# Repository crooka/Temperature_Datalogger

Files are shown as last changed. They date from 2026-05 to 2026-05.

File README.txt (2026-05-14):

Reach out to andrew.crook@usu.edu with any questions. 

Use 1 Oz copper
Green soldermask preferred

Most parts have links to both Digikey and JLCPCB. JLCPCB is the preferred supplier, but the big capacitors will need to come from digikey. 
UPDATE: due to cost, I'm only getting the top side assembled, and I'm not getting the ESP32 put on because that will drive up cost. Planning to put the ESP32 with solder paste and the reflow oven at work, and hand solder the back side. 

This section is so I can keep track of what's for what. 
Component purpose/notes:

R11,R12: 	Tell usb to send over 5V
C11,C13,C14,C15:Clean up power to sensors and some ESD protection
C7,C3,C6,C5: 	Clean up power from AMS1117
AMS1117: 	Linear voltage regulator to convert 5V to 3.3V (This is isn't as efficient as a buck converter)
D1: 		Probably not necessary, but this is back current protection. It was in the example. 
R5,R8:		Pull up resistors for the buttons

ESP32: 		This is the brains. Pushing the enable button should reset the board, The IO0 button should make it enter boot mode. 

TMP117: Maybe add in a zero ohm resistor option later so gpio16 can be used for either temperature interrupts or broken out for general IO depending on the assembly? 
	Verify that tying ADD0 to GND gives I2C address 0x48.
	Using recommended 4.7Kohm pull up resistor for SDA and SCL. One source said 2.2K may be better?  

BH1750: Tie ADDR to GND for I2C address 0x23

BME280 Tie CSB to VDDIO for I2C (tie to GND for SPI) With I2C selected, tie SDO to GND for I2C address 0x76

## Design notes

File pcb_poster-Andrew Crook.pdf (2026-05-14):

# Temperature Datalogger

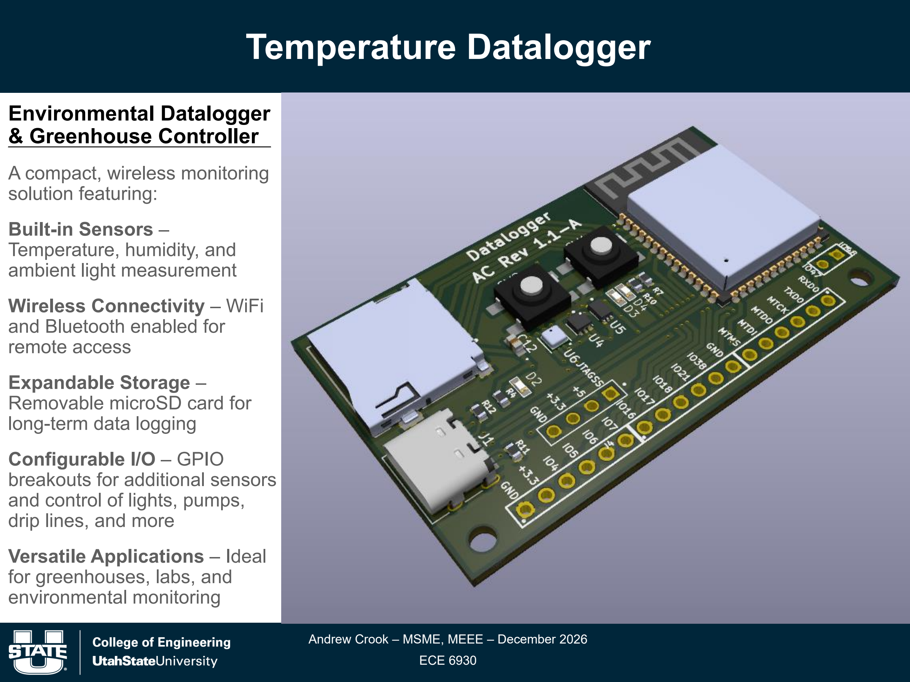
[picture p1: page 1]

Andrew Crook – MSME, MEEE – December 2026

ECE 6930

Environmental Datalogger
& Greenhouse Controller

A compact, wireless monitoring solution featuring:

Built-in Sensors –
Temperature, humidity, and ambient light measurement

Wireless Connectivity – WiFi and Bluetooth enabled for
remote access

Expandable Storage –
Removable microSD card for long-term data logging

Configurable I/O – GPIO
breakouts for additional sensors and control of lights, pumps, drip lines, and more

Versatile Applications – Ideal for greenhouses, labs, and environmental monitoring

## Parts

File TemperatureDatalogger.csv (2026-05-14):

Source: | C:\Users\gecko\Desktop\classes\pcb\TemperatureDatalogger\TemperatureDatalogger.kicad_sch
Date: | 2025-11-14T09:51:00-0700
Tool: | Eeschema 9.0.4
Generator: | C:\Program Files\KiCad\9.0\bin\scripting\plugins/bom_csv_grouped_by_value.py
Component Count: | 40
Collated Components:
Item | Qty | Reference(s) | Value | LibPart | Footprint | Datasheet | DNP | AVAILABILITY | Availability | Check_prices | DESCRIPTION | DPN | DPR | Datasheet | Description | Description_1 | Digikey Link (backup part) | Digikey link | Footprint | JLCPCB | JLCPCB link | MANUFACTURER | MAXIMUM_PACKAGE_HEIGHT | MF | MFR | MP | MPN | MRF | PACKAGE | PARTREV | PRICE | PURCHASE-URL | Package | Price | SPN | SPR | STANDARD | Sim.Pins | SnapEDA_Link | Untitled Field
1 | 2 | C1, C7 | 10uf RFS | WCAP-PSLP_4X5.5:WCAP-PSLP_4X5.5 | RF-A_NCH:RF-A_NCH-M | kicad-embed://e-rfs_rfa.pdf | DNP |  |  |  |  |  |  | kicad-embed://e-rfs_rfa.pdf |  |  |  | https://www.digikey.com/en/products/detail/nichicon/RFS1A100MCN1GB/2202796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 | RF-A_NCH:RF-A_NCH-M | https://jlcpcb.com/partdetail/Nichicon-RFS1A100MCN1GB/C2162094 |  |  |  |  | Nichicon |  | RFS1A100MCN1GB |  |  |  |  |  |  |  | 493-3682-1-ND | Digikey
2 | 9 | C2, C3, C4, C6, C11, C12, C13, C14, C15 | 100 nf | :CC0603KRX5R8BB104_1 | CC0603KRX5R8BB104:CAP_CC0603KRX5R8BB104_YAG-M | CC0603KRX5R8BB104 |  |  |  |  |  |  |  | CC0603KRX5R8BB104 |  |  |  | https://www.digikey.com/en/products/detail/yageo/CC0603KRX5R8BB104/20376210 | CC0603KRX5R8BB104:CAP_CC0603KRX5R8BB104_YAG-M |  | https://jlcpcb.com/partdetail/YAGEO-CC0603KRX5R8BB104/C2930551 |  |  |  | YAGEO |  | CC0603KRX5R8BB104 |  |  |  |  |  |  |  | C2930551 | JLCPCB
3 | 1 | C5 | 22uf WCAP | WCAP-PSLP_4X5.5:WCAP-PSLP_4X5.5 | WCAP-PSLP:WCAP-PSLP_4X5.5_DXL_ | kicad-embed://875105240003.pdf | DNP |  |  |  |  |  |  | kicad-embed://875105240003.pdf |  |  |  | https://www.digikey.com/en/products/detail/w%C3%BCrth-elektronik/875105240003/5147567 | WCAP-PSLP:WCAP-PSLP_4X5.5_DXL_ |  | https://jlcpcb.com/partdetail/WurthElektronik-875105240003/C2161805 |  |  |  | Wurth Elektronik |  | 875105240003 |  |  |  |  |  |  |  | 732-6403-1-ND - Cut Tape (CT) | Digikey
4 | 1 | D1 | D_Schottky | Device:D_Schottky | Schottkey:DO-214AC_VIS-M | kicad-embed://bys10.pdf |  |  |  |  |  |  |  | kicad-embed://bys10.pdf | Schottky diode |  |  | https://www.digikey.com/en/products/detail/vishay-general-semiconductor-diodes-division/BYS10-25-E3-TR/2149781 | Schottkey:DO-214AC_VIS-M |  | https://jlcpcb.com/partdetail/VishayIntertech-BYS10_25_E3TR/C3008962 |  |  |  | Vishay Intertech |  | BYS10-25-E3/TR |  |  |  |  |  |  |  | C3008962 | JLCPCB
5 | 2 | D2, D4 | Green LED | Device:LED | LED:LED_0604_SMD | kicad-embed://150060VS55040.pdf |  |  |  |  |  |  |  | kicad-embed://150060VS55040.pdf | Light emitting diode |  |  | https://www.digikey.com/en/products/detail/w%C3%BCrth-elektronik/150060VS55040/8557182 | LED:LED_0604_SMD |  | https://jlcpcb.com/partdetail/WurthElektronik-150060VS55040/C6390388 |  |  |  |  |  | 150060VS55040 | Würth Elektronik |  |  |  |  |  |  | C6390388 | JLCPCB |  | 1=K 2=A
6 | 1 | D3 | Red LED | Device:LED | LED:LED_0604_SMD | kicad-embed://150060VS55040.pdf |  |  |  |  |  |  |  | kicad-embed://150060VS55040.pdf | Light emitting diode |  |  | https://www.digikey.com/en/products/detail/w%C3%BCrth-elektronik/150060RS75000/4489901 | LED:LED_0604_SMD |  | https://jlcpcb.com/partdetail/WurthElektronik-150060RS75000/C3030991 |  |  |  |  |  | 150060RS75000 | Würth Elektronik |  |  |  |  |  |  | C3030991 | JLCPCB |  | 1=K 2=A
7 | 1 | J1 | USB_C_Receptacle_USB2.0_16P | Connector:USB_C_Receptacle_USB2.0_16P | Connector_USB:USB_C_Receptacle_HRO_TYPE-C-31-M-12 | kicad-embed://C165948.pdf |  |  |  |  |  |  |  | kicad-embed://C165948.pdf | USB 2.0-only 16P Type-C Receptacle connector |  |  |  | Connector_USB:USB_C_Receptacle_HRO_TYPE-C-31-M-12 |  | https://jlcpcb.com/partdetail/Korean_HropartsElec-TYPE_C_31_M12/C165948 |  |  |  | Korean Hroparts Elec |  | TYPE-C-31-M-12 |  |  |  |  |  |  |  | C165948 | JLCPCB
8 | 1 | J2 | Micro_SD_Card | TF-01A:TF-01A | TF_01A:TF-01A | https://www.we-online.com/components/products/datasheet/693072010801.pdf |  |  | Not in stock | https://www.snapeda.com/parts/TF-01A/HRO+Electronics+Co.%252C+Ltd./view-part/?ref=eda |  |  |  | https://www.we-online.com/components/products/datasheet/693072010801.pdf | Micro SD Card Socket | Standard Card Edge Connectors |  |  | TF_01A:TF-01A |  | https://jlcpcb.com/parts/componentSearch?searchTxt=tf-01a |  |  | HRO Electronics Co., Ltd. | Korean Hroparts Elec | TF-01A | TF-01A |  |  |  |  |  | Package | None | C91145 | JLCPCB |  |  | https://www.snapeda.com/parts/TF-01A/HRO+Electronics+Co.%252C+Ltd./view-part/?ref=snap
9 | 3 | J3, J4, J15 | 6130XX11121_61300611121 | 6130XX11121_61300611121:6130XX11121_61300611121 | header6pin:61300611121 |  | DNP |  |  |  |  |  |  |  |  |  |  |  | header6pin:61300611121
10 | 1 | J5 | 61300411121 | 61300411121:61300411121 | header2_4pin:WURTH_61300411121 |  | DNP | In Stock |  |  | Connector Header Through Hole 4 position 0.100 (2.54mm) |  |  |  | Connector Header Through Hole 4 position 0.100 (2.54mm) |  |  |  | header2_4pin:WURTH_61300411121 |  |  |  |  | Würth Elektronik |  | 61300411121 |  |  | None |  | None | https://pricing.snapeda.com/search/part/61300411121/?ref=eda
11 | 1 | J6 | TSW-102-07-F-S | TSW-102-07-F-S:TSW-102-07-F-S | header2_4pin:SAMTEC_TSW-102-07-F-S |  | DNP |  |  |  |  |  |  |  |  |  |  |  | header2_4pin:SAMTEC_TSW-102-07-F-S |  |  | Samtec |  |  |  |  |  |  |  | R |  |  |  |  |  |  | Manufacturer Recommendations
12 | 2 | R1, R2 | 4.7K | RCS06035K10FKEA:RCS06035K10FKEA | 0_27k:RES_ERJPA3F2700V | kicad-embed://C4017867.pdf |  |  |  |  |  |  |  | kicad-embed://C4017867.pdf |  |  |  | https://www.digikey.com/en/products/detail/yageo/RC0603FR-074K7L/727212 | 0_27k:RES_ERJPA3F2700V |  | https://jlcpcb.com/partdetail/YAGEO-RC0603FR074K7L/C99782 |  |  |  | YAGEO |  | RC0603FR-074K7L |  |  |  |  |  |  |  | C99782 | JLCPCB
13 | 3 | R4, R7, R10 | 0.27k | RCS06035K10FKEA:RCS06035K10FKEA | 0_27k:RES_ERJPA3F2700V | kicad-embed://C4017867.pdf |  |  |  |  |  |  |  | kicad-embed://C4017867.pdf |  |  |  | https://www.digikey.com/en/products/detail/yageo/RC0603FR-13270RL/14286751 | 0_27k:RES_ERJPA3F2700V |  | https://jlcpcb.com/partdetail/YAGEO-RC0603FR13270RL/C4017867 |  |  |  | YAGEO |  | RC0603FR-13270RL |  |  |  |  |  |  |  | C4017867 | JLCPCB
14 | 2 | R5, R8 | 10k | RCS06035K10FKEA:RCS06035K10FKEA | 0_27k:RES_ERJPA3F2700V | kicad-embed://C4017867.pdf |  |  |  |  |  |  |  | kicad-embed://C4017867.pdf |  |  |  | https://www.digikey.com/en/products/detail/yageo/RC0603FR-0710KL/726880 | 0_27k:RES_ERJPA3F2700V |  | https://jlcpcb.com/partdetail/YAGEO-RC0603FR0710KL/C98220 |  |  |  | YAGEO |  | RC0603FR-0710KL |  |  |  |  |  |  |  | C98220 | JLCPCB
15 | 2 | R11, R12 | 5.1K | RCS06035K10FKEA:RCS06035K10FKEA | 0_27k:RES_ERJPA3F2700V | kicad-embed://C4017867.pdf |  |  |  |  |  |  |  | kicad-embed://C4017867.pdf |  |  |  | https://www.digikey.com/en/products/detail/yageo/RC0603FR-075K1L/727268 | 0_27k:RES_ERJPA3F2700V |  | https://jlcpcb.com/partdetail/YAGEO-RC0603FR075K1L/C105580 |  |  |  | YAGEO |  | RC0603FR-075K1L |  |  |  |  |  |  |  | C105580 | JLCPCB
16 | 2 | SW1, SW2 | SW_MEC_5E | Switch:SW_MEC_5E | TactileButton:button | kicad-embed://C306883.pdf |  |  |  |  |  |  |  | kicad-embed://C306883.pdf | MEC 5E single pole normally-open tactile switch |  |  | https://www.digikey.com/en/products/detail/omron-electronics-inc-emc-div/B3SN-3012P/9717 | TactileButton:button |  | https://jlcpcb.com/partdetail/OmronElectronics-B3SN3012P/C306881 |  |  |  | Omron Electronics |  | B3SN-3012P |  |  |  |  |  |  |  | C306881 | JLCPCB
17 | 1 | U1 | ESP32-S3-WROOM-1-N4 | ESP32-S3-WROOM-1-N4:ESP32-S3-WROOM-1-N4 | esp32:XCVR_ESP32-S3-WROOM-1-N4 | kicad-embed://esp32-s3-wroom-1_wroom-1u_datasheet_en.pdf |  |  |  |  |  |  |  | kicad-embed://esp32-s3-wroom-1_wroom-1u_datasheet_en.pdf |  |  |  | https://www.digikey.com/en/products/detail/espressif-systems/ESP32-S3-WROOM-1-N4/16162639 | esp32:XCVR_ESP32-S3-WROOM-1-N4 |  | https://jlcpcb.com/partdetail/3198295-ESP32_S3_WROOM_1N4/C2913197 | Espressif | 3.25mm |  | Espressif Systems |  | ESP32-S3-WROOM-1-N4 |  |  | v1.0 |  |  |  |  | C2913197 | JLCPCB | Manufacturer Recommendations
18 | 1 | U2 | USBLC6-2SC6 | USBLC6-2SC6:USBLC6-2SC6 | USBLC6:SOT95P280X145-6N | kicad-embed://en.CD00050750.pdf |  | In Stock | In Stock | https://www.snapeda.com/parts/USBLC6-2SC6/STMicroelectronics/view-part/?ref=eda | 17V Clamp 5A (8/20µs) Ipp Tvs Diode Surface Mount SOT-23-6 | C7519 | JLCPCB | kicad-embed://en.CD00050750.pdf | ESD protection for USB C | 17V Clamp 5A (8/20µs) Ipp Tvs Diode Surface Mount SOT-23-6 |  | https://www.digikey.com/en/products/detail/stmicroelectronics/USBLC6-2SC6/1040559 | USBLC6:SOT95P280X145-6N |  | https://jlcpcb.com/partdetail/STMicroelectronics-USBLC62SC6/C7519 |  |  | STMicroelectronics | STMicroelectronics | USBLC6-2SC6 | USBLC6-2SC6 |  | SOT-23-6 STMicroelectronics |  | None | https://pricing.snapeda.com/search/part/USBLC6-2SC6/?ref=eda | SOT-23-6 STMicroelectronics | None |  |  |  |  | https://www.snapeda.com/parts/USBLC6-2SC6/STMicroelectronics/view-part/?ref=snap
19 | 1 | U3 | AMS1117-3.3 | AMS1117-3.3:AMS1117-3.3 | AMS1117:SOT229P700X180-4N | kicad-embed://C6186.pdf |  | Unavailable | In Stock | https://www.snapeda.com/parts/AMS1117-3.3/UMW/view-part/?ref=eda |  |  |  | kicad-embed://C6186.pdf |  | Linear Voltage Regulator IC Positive Fixed 1 Output 1A SOT-223-3L | https://www.digikey.com/en/products/detail/evvo/AMS1117-3-3/22482148 |  | AMS1117:SOT229P700X180-4N |  | https://jlcpcb.com/partdetail/Advanced_MonolithicSystems-AMS1117_33/C6186 | Advanced Mololithic Systems |  | UMW | Advanced Monolithic Systems | AMS1117-3.3 | AMS1117-3.3 |  | SOT-223 ams | NA | None |  | SOT-223-3L UMW | None | C6186 | JLCPCB | IPC-7351B |  | https://www.snapeda.com/parts/AMS1117-3.3/UMW/view-part/?ref=snap
20 | 1 | U4 | TMP117MAIDRVR | TMP117MAIDRVR:TMP117MAIDRVR | TMP117:SON65P200X200X80-7N | kicad-embed://tmp117.pdf |  |  |  |  |  |  |  | kicad-embed://tmp117.pdf |  |  |  | https://www.digikey.com/en/products/detail/texas-instruments/TMP117MAIDRVR/9685285 | TMP117:SON65P200X200X80-7N |  | https://jlcpcb.com/partdetail/TexasInstruments-TMP117MAIDRVR/C2803242 |  |  |  | Texas Instruments |  | TMP117MAIDRVR |  |  |  |  |  |  |  | C2803242 | JLCPCB
21 | 1 | U5 | BH1750FVI-TR | BH1750FVI-TR:BH1750FVI-TR | BH1750:XDCR_BH1750FVI-TR | kicad-embed://bh1750fvi-e.pdf |  |  |  |  |  |  |  | kicad-embed://bh1750fvi-e.pdf |  |  |  | https://www.digikey.com/en/products/detail/rohm-semiconductor/BH1750FVI-TR/2041441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 | BH1750:XDCR_BH1750FVI-TR |  | https://jlcpcb.com/partdetail/ROHMSemicon-BH1750FVITR/C78960 | Rohm | 0.75mm |  | ROHM Semicon |  | BH1750FVI-TR |  |  | D |  |  |  |  | C78960 | JLCPCB | Manufacturer recommendations
22 | 1 | U6 | BME280 | BME280:BME280 | BME280:PSON65P250X250X100-8N | kicad-embed://bst-bme280-ds002.pdf |  | Good |  |  | Integrated pressure, humidity and temperature sensor; 8-pin 2.5x2.5x0.93mm LGA |  |  | kicad-embed://bst-bme280-ds002.pdf | Integrated pressure, humidity and temperature sensor; 8-pin 2.5x2.5x0.93mm LGA |  |  | https://www.digikey.com/en/products/detail/bosch-sensortec/BME280/6136306 | BME280:PSON65P250X250X100-8N |  | https://jlcpcb.com/parts/componentSearch?searchTxt=BME280 |  |  | Bosch | Bosch Sensortec | BME280 | BME280 |  | LGA-8 Bosch |  | 4.94 USD |  |  |  | C92489 | JLCPCB | IPC-7351B

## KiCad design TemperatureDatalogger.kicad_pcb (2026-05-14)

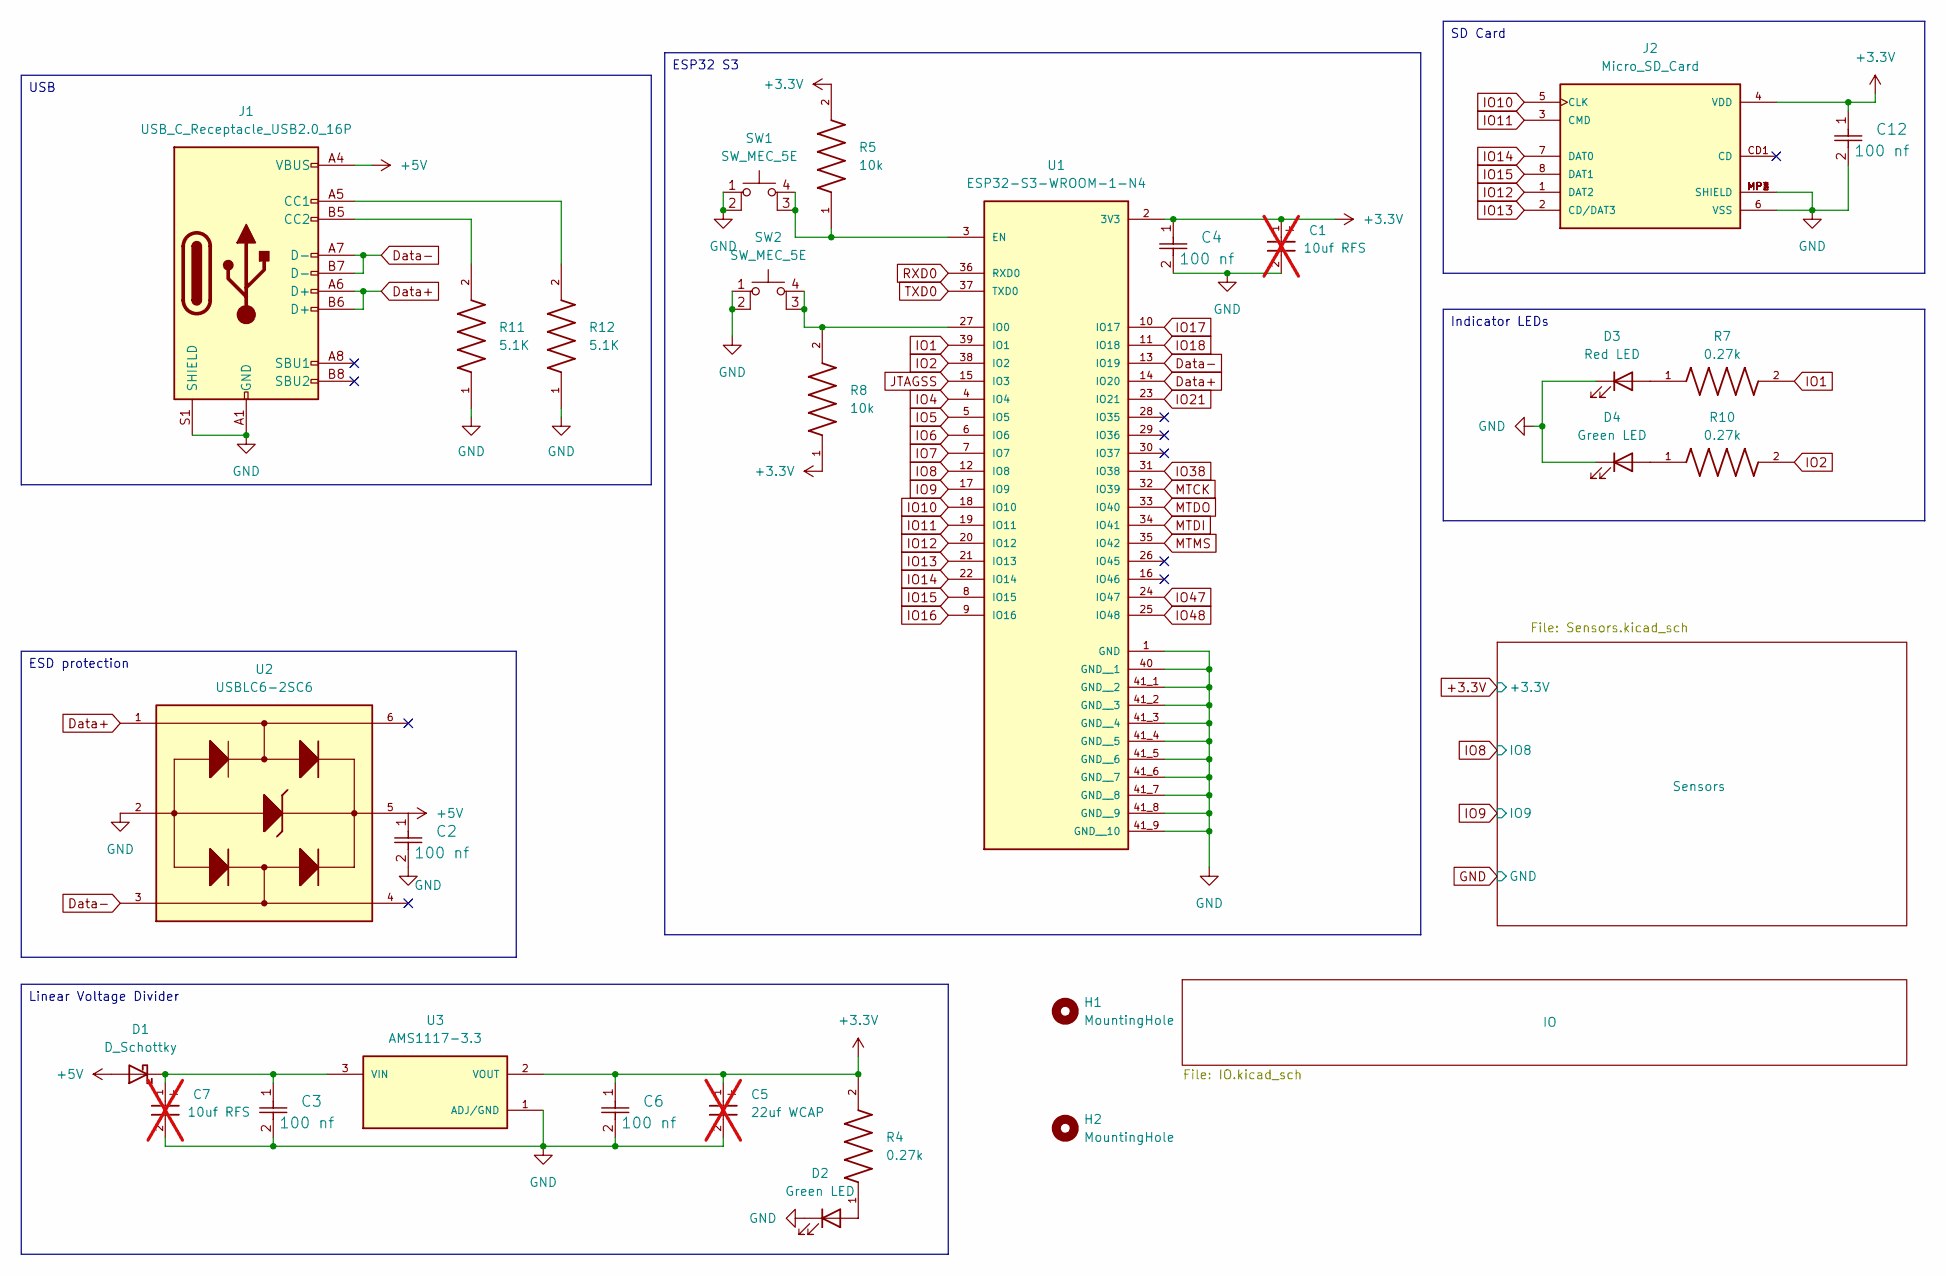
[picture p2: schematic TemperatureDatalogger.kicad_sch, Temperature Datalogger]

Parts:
C1, C7: 10uf RFS; RF-A_NCH-M; MPN RFS1A100MCN1GB; not fitted
C2, C3, C4, C6, C12: 100 nf; CAP_CC0603KRX5R8BB104_YAG-M; MPN CC0603KRX5R8BB104
C5: 22uf WCAP; WCAP-PSLP_4X5.5_DXL_; MPN 875105240003; not fitted
D1: D_Schottky; DO-214AC_VIS-M; MPN BYS10-25-E3/TR
D2, D4: Green LED; LED_0604_SMD; MPN 150060VS55040
D3: Red LED; LED_0604_SMD; MPN 150060RS75000
H1, H2: MountingHole; MountingHole_2.7mm_M2.5_ISO14580
J1: USB_C_Receptacle_USB2.0_16P; USB_C_Receptacle_HRO_TYPE-C-31-M-12; MPN TYPE-C-31-M-12
J2: Micro_SD_Card; TF-01A; MPN TF-01A
R4, R7, R10: 0.27k; RES_ERJPA3F2700V; MPN RC0603FR-13270RL
R5, R8: 10k; RES_ERJPA3F2700V; MPN RC0603FR-0710KL
R11, R12: 5.1K; RES_ERJPA3F2700V; MPN RC0603FR-075K1L
SW1, SW2: SW_MEC_5E; button; MPN B3SN-3012P
U1: ESP32-S3-WROOM-1-N4; XCVR_ESP32-S3-WROOM-1-N4; PARTREV v1.0
U2: USBLC6-2SC6; SOT95P280X145-6N; MPN USBLC6-2SC6
U3: AMS1117-3.3; SOT229P700X180-4N; PARTREV NA

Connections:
+3.3V: C1.1, C4.1, C5.1, C6.1, C12.1, J2.4 (VDD), R4.2, R5.2, R8.1, U1.2 (3V3), U3.2 (VOUT); also elsewhere on the board
+5V: C2.1, D1.2 (A), J1.A4 (VBUS), J1.A9 (VBUS), J1.B4 (VBUS), J1.B9 (VBUS), U2.5; also elsewhere on the board
Data+: J1.A6 (D+), J1.B6 (D+), U1.14 (IO20), U2.1
Data-: J1.A7 (D-), J1.B7 (D-), U1.13 (IO19), U2.3
GND: C1.2, C2.2, C3.2, C4.2, C5.2, C6.2, C7.2, C12.2, D2.1 (K), D3.1 (K), D4.1 (K), J1.A1 (GND), J1.A12 (GND), J1.B1 (GND), J1.B12 (GND), J1.S1 (SHIELD), J2.6 (VSS), J2.MP1 (SHIELD), J2.MP2 (SHIELD), J2.MP3 (SHIELD), J2.MP4 (SHIELD), R11.1, R12.1, SW1.1, SW1.2, SW2.1, SW2.2, U1.1 (GND), U1.40 (GND__1), U1.41_1 (GND__2), U1.41_2 (GND__3), U1.41_3 (GND__4), U1.41_4 (GND__5), U1.41_5 (GND__6), U1.41_6 (GND__7), U1.41_7 (GND__8), U1.41_8 (GND__9), U1.41_9 (GND__10), U1.41_10, U1.41_11, U1.41_12, U1.41_13, U1.41_14, U1.41_15, U1.41_16, U1.41_17, U1.41_18, U1.41_19, U1.41_20, U1.41_21, U2.2, U3.1 (ADJ/GND); also elsewhere on the board
IO1: R7.2, U1.39 (IO1)
IO2: R10.2, U1.38 (IO2)
IO4: U1.4 (IO4); also elsewhere on the board
IO5: U1.5 (IO5); also elsewhere on the board
IO6: U1.6 (IO6); also elsewhere on the board
IO7: U1.7 (IO7); also elsewhere on the board
IO8: U1.12 (IO8); also elsewhere on the board
IO9: U1.17 (IO9); also elsewhere on the board
IO10: J2.5 (CLK), U1.18 (IO10)
IO11: J2.3 (CMD), U1.19 (IO11)
IO12: J2.1 (DAT2), U1.20 (IO12)
IO13: J2.2 (CD/DAT3), U1.21 (IO13)
IO14: J2.7 (DAT0), U1.22 (IO14)
IO15: J2.8 (DAT1), U1.8 (IO15)
IO16: U1.9 (IO16); also elsewhere on the board
IO17: U1.10 (IO17); also elsewhere on the board
IO18: U1.11 (IO18); also elsewhere on the board
IO21: U1.23 (IO21); also elsewhere on the board
IO38: U1.31 (IO38); also elsewhere on the board
IO47: U1.24 (IO47); also elsewhere on the board
IO48: U1.25 (IO48); also elsewhere on the board
JTAGSS: U1.15 (IO3); also elsewhere on the board
MTCK: U1.32 (IO39); also elsewhere on the board
MTDI: U1.34 (IO41); also elsewhere on the board
MTDO: U1.33 (IO40); also elsewhere on the board
MTMS: U1.35 (IO42); also elsewhere on the board
unnamed: C3.1, C7.1, D1.1 (K), U3.3 (VIN)
unnamed: D2.2 (A), R4.1
unnamed: D3.2 (A), R7.1
unnamed: D4.2 (A), R10.1
unnamed: J1.A5 (CC1), R12.2
unnamed: J1.B5 (CC2), R11.2
unnamed: R5.1, SW1.3 (K), SW1.4 (A), U1.3 (EN)
unnamed: R8.2, SW2.3 (K), SW2.4 (A), U1.27 (IO0)
RXD0: U1.36 (RXD0); also elsewhere on the board
TXD0: U1.37 (TXD0); also elsewhere on the board

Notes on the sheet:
USB
ESP32 S3
Linear Voltage Divider
SD Card
ESD protection
Indicator LEDs

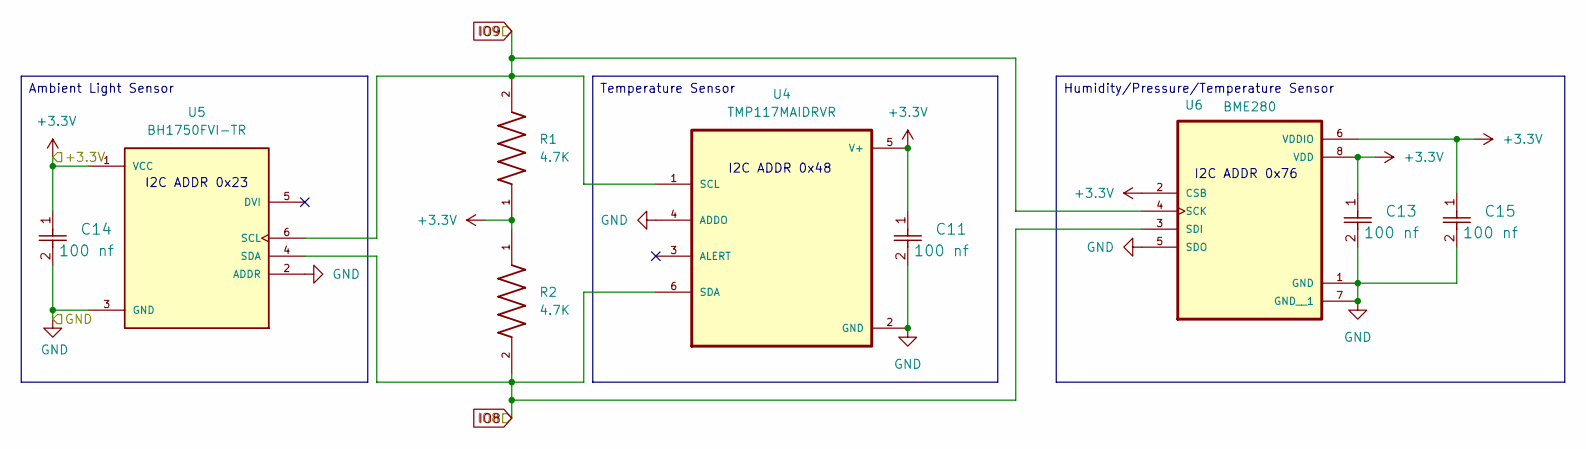
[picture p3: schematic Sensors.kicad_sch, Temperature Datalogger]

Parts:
C11, C13, C14, C15: 100 nf; CAP_CC0603KRX5R8BB104_YAG-M; MPN CC0603KRX5R8BB104
R1, R2: 4.7K; RES_ERJPA3F2700V; MPN RC0603FR-074K7L
U4: TMP117MAIDRVR; SON65P200X200X80-7N; MPN TMP117MAIDRVR
U5: BH1750FVI-TR; XDCR_BH1750FVI-TR; PARTREV D
U6: BME280; PSON65P250X250X100-8N; MPN BME280

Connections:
+3.3V: C11.1, C13.1, C14.1, C15.1, R1.1, R2.1, U4.5 (V+), U5.1 (VCC), U6.2 (CSB), U6.6 (VDDIO), U6.8 (VDD); also elsewhere on the board
GND: C11.2, C13.2, C14.2, C15.2, U4.2 (GND), U4.4 (ADDO), U4.7, U5.2 (ADDR), U5.3 (GND), U6.1 (GND), U6.5 (SDO), U6.7 (GND__1); also elsewhere on the board
IO8: R2.2, U4.6 (SDA), U5.4 (SDA), U6.3 (SDI); also elsewhere on the board
IO9: R1.2, U4.1 (SCL), U5.6 (SCL), U6.4 (SCK); also elsewhere on the board

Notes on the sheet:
I2C ADDR 0x23
I2C ADDR 0x48
I2C ADDR 0x76
Temperature Sensor
Ambient Light Sensor
Humidity/Pressure/Temperature Sensor

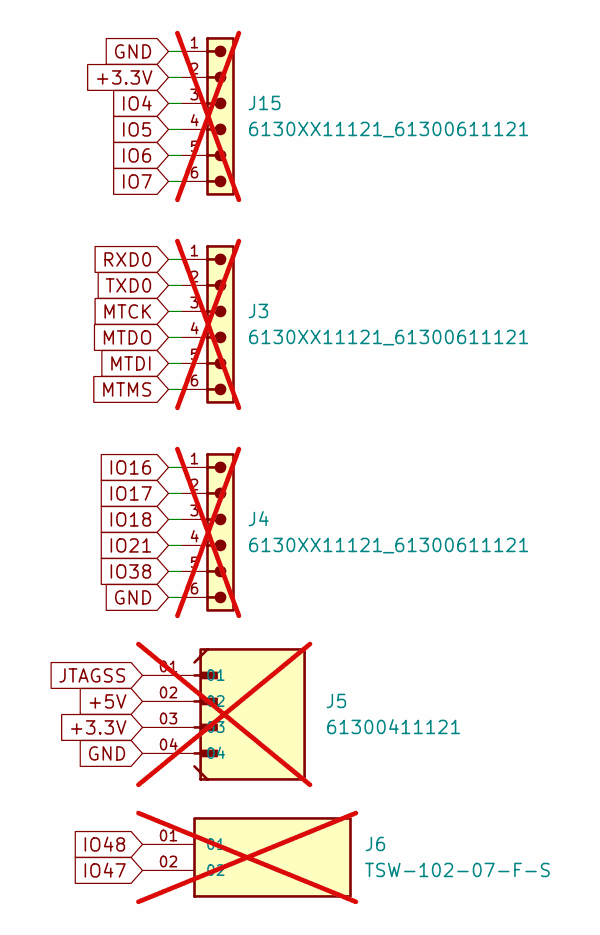
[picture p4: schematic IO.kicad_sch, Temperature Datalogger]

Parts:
J3, J4, J15: 6130XX11121_61300611121; 61300611121; not fitted
J5: 61300411121; WURTH_61300411121; not fitted
J6: TSW-102-07-F-S; SAMTEC_TSW-102-07-F-S; PARTREV R; not fitted

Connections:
+3.3V: J5.03, J15.2; also elsewhere on the board
+5V: J5.02; also elsewhere on the board
GND: J4.6, J5.04, J15.1; also elsewhere on the board
IO4: J15.3; also elsewhere on the board
IO5: J15.4; also elsewhere on the board
IO6: J15.5; also elsewhere on the board
IO7: J15.6; also elsewhere on the board
IO16: J4.1; also elsewhere on the board
IO17: J4.2; also elsewhere on the board
IO18: J4.3; also elsewhere on the board
IO21: J4.4; also elsewhere on the board
IO38: J4.5; also elsewhere on the board
IO47: J6.02; also elsewhere on the board
IO48: J6.01; also elsewhere on the board
JTAGSS: J5.01; also elsewhere on the board
MTCK: J3.3; also elsewhere on the board
MTDI: J3.5; also elsewhere on the board
MTDO: J3.4; also elsewhere on the board
MTMS: J3.6; also elsewhere on the board
RXD0: J3.1; also elsewhere on the board
TXD0: J3.2; also elsewhere on the board

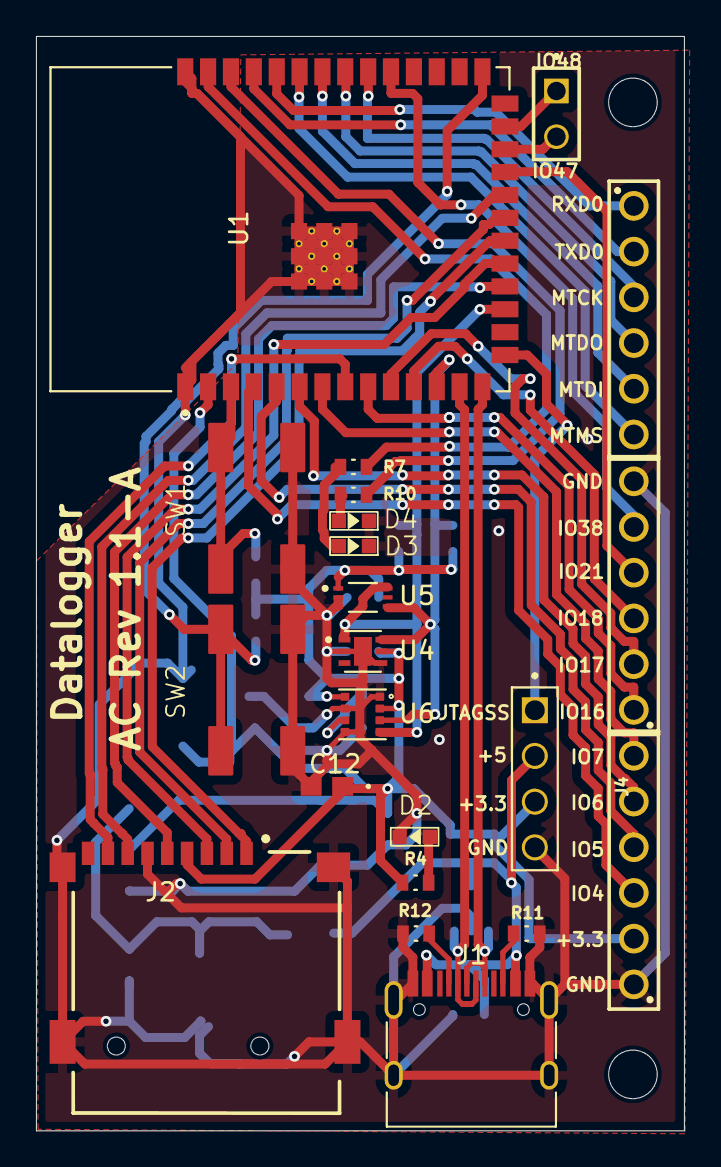
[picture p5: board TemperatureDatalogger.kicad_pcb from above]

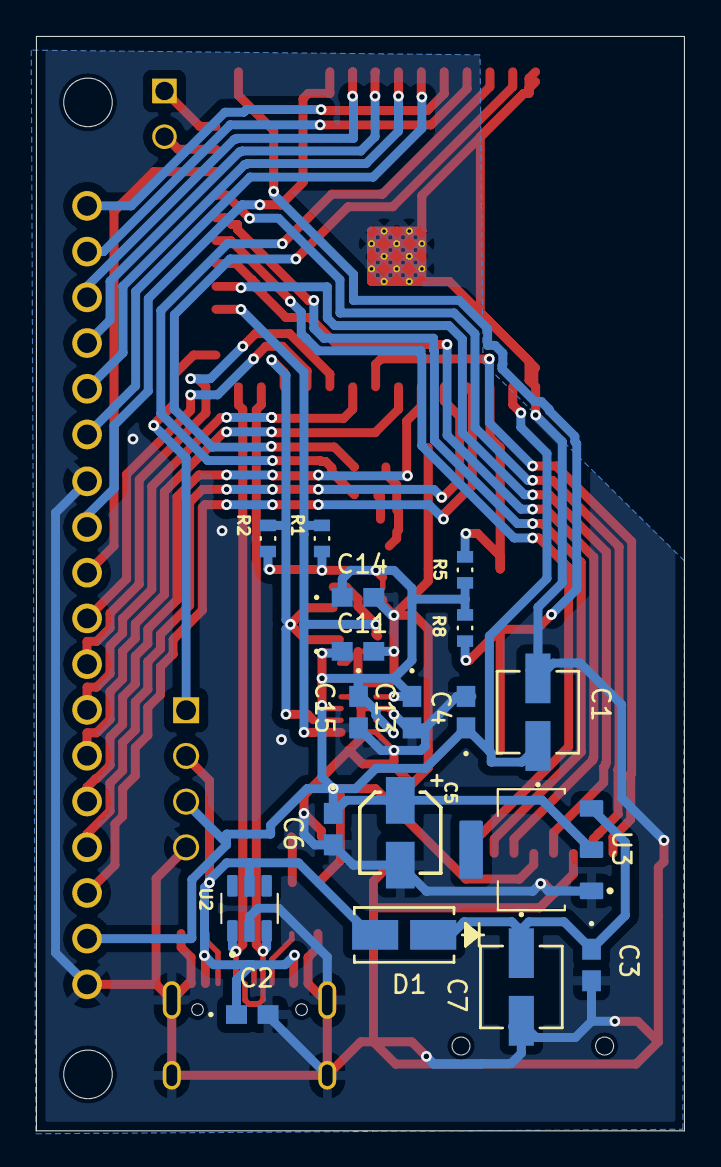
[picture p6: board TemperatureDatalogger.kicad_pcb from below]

Board: 2 copper layers, 36.0 x 60.8 mm, 42 parts (18 on the bottom side), 41 nets.
